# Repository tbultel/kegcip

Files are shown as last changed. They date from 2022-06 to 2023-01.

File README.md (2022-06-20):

# kegcip

CIP controller for Beer Tanks and Kegs

Inspired from various existing CIP (Clean In Place) Open Source projects, this one
aim to be a kind of best-off, leveraging the original designers spirit and 
brilliant ideas, but trying to bring more robustness, and reusability.

We only focus here on the microcontroller code and hardware.

The chosen microcontroler is the Teensy 4.0
The application works fine with Teensy 3.1 as well, but it is end of life and sold out.

For simplicity and readabiliy, the code stronly relies on TeensyThreads https://github.com/ftrias/TeensyThreads

# Setup

You need an arduino + teensy toolchain setup, please see on Teensy site how to make it.
The top Makefile lists the needed librairies, that can be installed, for instance,
via the Arduino IDE.

* U8g2: graphical library for SSD1309 LCD chips. Uses hardware SPI.
* Wire: i2C support (for the relays board)
* DallasTemperature: to read the temperature sensor, needs OneWire
* SPI: see above
* RotaryEncoder: support of rotary buttn plugged on GPIOs
* OneWire: see above
* TeensyThreads: for modern and efficient code !
* Bounce2: de-bouncing GPIO in reads
* EEPROM: support of built-in EEPROM in Teensy board, for horameters

# Building

Clone with recurse option, or perform a 
``` 
git submodule update --init
```
Then it's simple:

``` 
make clean && make -j && make flash
```

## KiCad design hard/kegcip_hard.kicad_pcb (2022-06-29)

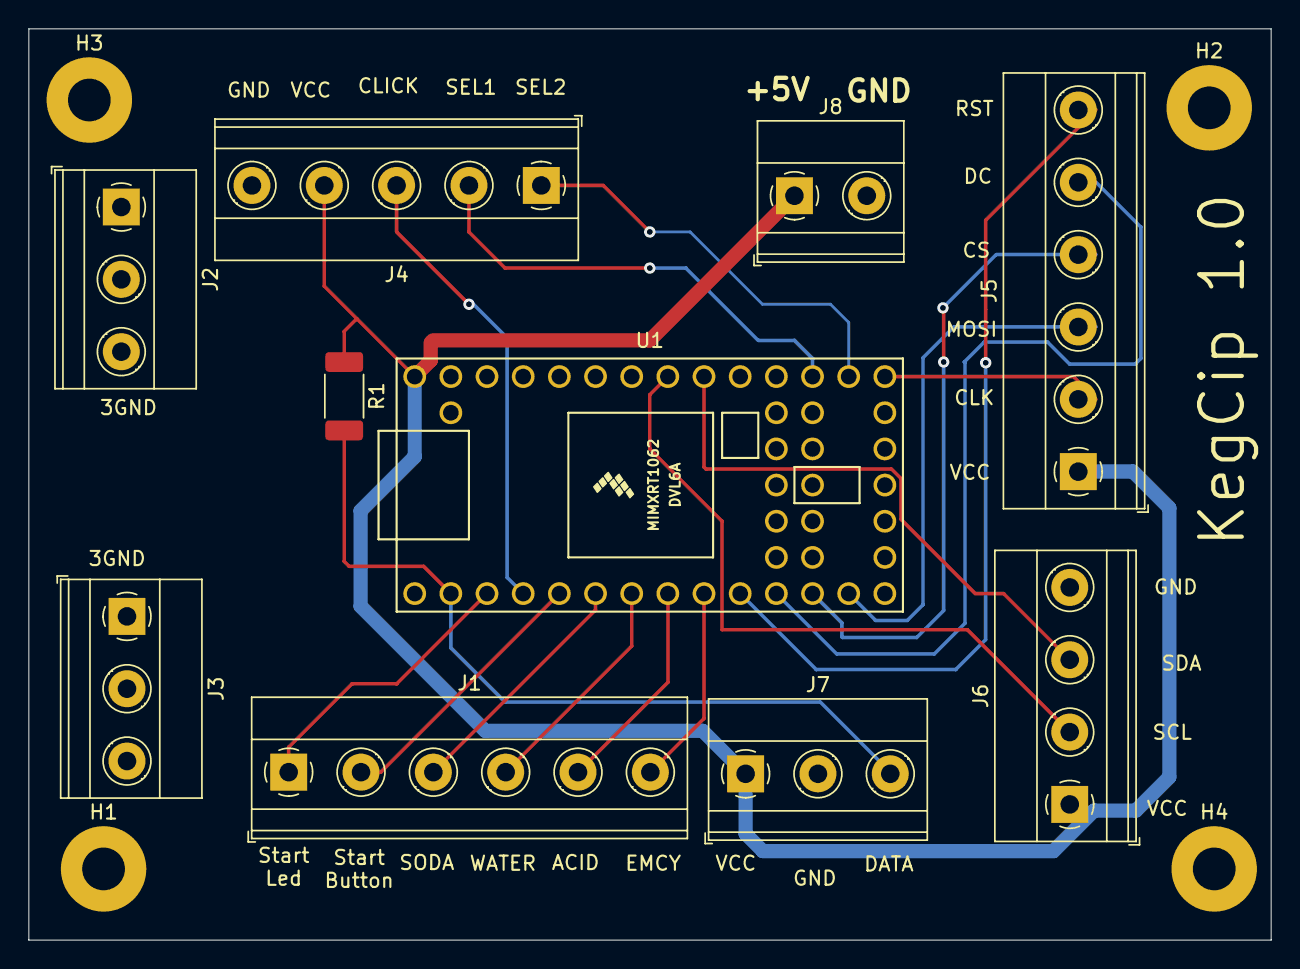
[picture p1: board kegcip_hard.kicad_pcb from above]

Board: 2 copper layers, 87.2 x 64.0 mm, 14 parts (0 on the bottom side), 19 nets.

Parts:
H1, H2, H3, H4: MountingHole; MountingHole_3mm_Pad
J1: I/O; TerminalBlock_Phoenix_MKDS-1,5-6-5.08_1x06_P5.08mm_Horizont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
J2: GND1; TerminalBlock_Phoenix_MKDS-1,5-3-5.08_1x03_P5.08mm_Horizont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
J3: GND2; TerminalBlock_Phoenix_MKDS-1,5-3-5.08_1x03_P5.08mm_Horizont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
J4: ROTARY; TerminalBlock_Phoenix_MKDS-1,5-5-5.08_1x05_P5.08mm_Horizont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
J5: LCD; TerminalBlock_Phoenix_MKDS-1,5-6-5.08_1x06_P5.08mm_Horizont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
J6: Relays; TerminalBlock_Phoenix_MKDS-1,5-4-5.08_1x04_P5.08mm_Horizont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
J7: Temp; TerminalBlock_Phoenix_MKDS-1,5-3-5.08_1x03_P5.08mm_Horizont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
J8: PWR; TerminalBlock_Phoenix_MKDS-1,5-2-5.08_1x02_P5.08mm_Horizont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
R1: 47k; R_2010_5025Metric_Pad1.40x2.65mm_HandSolder
U1: Teensy4.0; Teensy40

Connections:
+5V: J4.4, J5.1, J6.1, J7.1, J8.1, R1.1, U1.33 (VIN)
/ACID_LOW: J1.5, U1.8 (6_OUT1D)
/EMERGENCY_STOP: J1.6, U1.9 (7_RX2_OUT1A)
/LCD_CLK: J5.2, U1.20 (13_SCK_CRX1_LED)
/LCD_DC: J5.5, U1.11 (9_OUT1C)
/LCD_RST: J5.6, U1.10 (8_TX2_IN1)
/LCD_SPI_CS: J5.4, U1.12 (10_CS_MQSR)
/LCD_SPI_MOSI: J5.3, U1.13 (11_MOSI_CTX1)
/ROT_CLICK: J4.3, U1.4 (2_OUT2)
/ROT_SEL1: J4.2, U1.22 (15_A1_RX3_SPDIF_IN)
/ROT_SEL2: J4.1, U1.21 (14_A0_TX3_SPDIF_OUT)
/SCL: J6.2, U1.26 (19_A5_SCL0)
/SDA: J6.3, U1.25 (18_A4_SDA0)
/SODA_LOW: J1.3, U1.6 (4_BCLK2)
/START_BUTTON: J1.2, U1.5 (3_LRCLK2)
/START_LED: J1.1, U1.3 (1_TX1_CTX2_MISO1)
/TEMP_DATA: J7.3, R1.2, U1.2 (0_RX1_CRX2_CS1)
/WATER_LOW: J1.4, U1.7 (5_IN2)
GND: H1.1, H2.1, H3.1, H4.1, J2.1, J2.2, J2.3, J3.1, J3.2, J3.3, J4.5, J6.4, J7.2, J8.2, U1.1 (GND), U1.17 (GND), U1.32 (GND)

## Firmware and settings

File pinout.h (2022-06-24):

#pragma once

// kegcip needs 14 GPIOS and 3 HW spi pins
// (think about when wanting to replace the µC !)

#define PIN_ONE_WIRE_BUS	0

#define PIN_BUTTON_LED		1
#define PIN_MENUCLICK		2
#define PIN_START_BUTTON	3
#define PIN_SODA_LOW		4
#define PIN_WATER_LOW		5
#define PIN_ACID_LOW		6
#define PIN_EMERGENCY_STOP	7

#define PIN_LCD_RST			8
#define PIN_LCD_DC			9
#define PIN_LCD_SPI_CS		10	// HW SPI
#define PIN_LCD_SPI_MOSI	11	// HW SPI
#define PIN_LCD_SPI_CLK		13	// HW SPI

#define PIN_MENUSELECT_1	14
#define PIN_MENUSELECT_2	15

#define PIN_RELAYS_SDA		18
#define PIN_RELAYS_SCL		19

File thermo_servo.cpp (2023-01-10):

#include <Arduino.h>
#include <stdio.h>

#include "thermo_servo.h"
#include "thread.h"
#include "temperature.h"
#include "relays.h"
#include "logical_output.h"
#include "display.h"
#include "main_menu.h"
#include "start_button.h"
#include "cycles.h"
#include "rotary_button.h"

static float thermo_setpoint = 0.0;
static float thermo_target_setpoint = THERMO_SERVO_TEMP_DEFAULT;

static int thermoServoThreadId = -1;
static bool thermo_is_on = false;
static bool initialized = false;
static bool ready = false;

static void thermo_servo_set_setpoint(float setpoint);
static void thermo_servo_set_target_setpoint(float target_setpoint);

#define THERMO_SERVO_THREAD_PERIOD_MS	500

static void thermo_servo_thread() {
	ready = true;
	printf("Thermo thread ready\n");

	bool heating = false;
	bool alarm = false;

	float old_temp = 0.0;
	uint32_t oldtimeSecs = 0;

	while (true) {
		float temp = temperature_get();

		char tempS[8], setpointS[8];
		dtostrf(temp, 4, 2, tempS);
		dtostrf(thermo_setpoint, 4, 2, setpointS);
#if DEBUG
		printf("%s: temp %s/%s\n", __func__, tempS, setpointS);
#endif		

		if (thermo_is_on && temp < thermo_setpoint) {
			if (!heating) {
				printf("%s: heating ...\n", __func__);
				old_temp=temperature_get();
				oldtimeSecs=millis()/1000;
			}

			heating = true;

		}
		else {
			if (heating)
				printf("%s: stopped heating ...\n", __func__);

			heating = false;
		}

		/* check the temperature delta */
		if (heating) {
			uint32_t elapsedSecs = millis()/1000;

			printf("thermal countdown: %d\n", THERMO_SERVO_1_DEG_TIME_SECS - (elapsedSecs - oldtimeSecs));

			// Check the temperature change each THERMO_SERVO_1_DEG_TIME_SECS interval, expect it to rise of at least 1 deg C
			if (elapsedSecs - oldtimeSecs >= THERMO_SERVO_1_DEG_TIME_SECS) {
				oldtimeSecs = elapsedSecs;

				char old_tempS[8];
				dtostrf(old_temp, 4, 2, old_tempS);

				printf("Check temp rising (old %s (%d), current %s (%d))\n", old_tempS, (int)old_temp, tempS, (int)temp);

				// Do not check the temperature delta if it is decreasing. (can happen when fresh soda comes back into the tank)
				if (temp > old_temp && (temp-old_temp < 1.0)) {
					alarm = true;
				}
				old_temp = temp;
			}
		}

		// check the heating timeout 
		if (alarm) {
			cycle_stop();
			thermo_off();
			logical_output_set(RELAYS_OFF);
			main_menu_disable();
			start_button_disable();
			rotary_button_disable();
			display_set_context(ALARM_CONTEXT);
			printf("ERROR: temperature runwaway !\n");
			// Dies here
			for (;;) {}
		}

		if (heating) {
			display_heating(true);
			relays_set_relay_on(THERM);
		}
		else {
			display_heating(false);
			relays_set_relay_off(THERM);
		}

		threads.delay(THERMO_SERVO_THREAD_PERIOD_MS);
	}
}

void thermo_servo_init() {
	if (initialized)
		return;

	printf("** Initializing thermo servo thread\n");
	thermoServoThreadId = threads.addThread(thermo_servo_thread, 0);
	while (!ready) { delay(100); }
}

static void thermo_servo_set_setpoint(float setpoint) {

	if (setpoint < 0.0)
		setpoint = 0.0;

	if (setpoint > THERMO_SERVO_TEMP_MAX)
		setpoint = THERMO_SERVO_TEMP_MAX;

	thermo_setpoint = setpoint;

	char tempS[8];
    dtostrf(thermo_setpoint, 4, 1, tempS);
	printf("thermo setpoint set to %s\n", tempS);
	
	display_thread_wakeup();
}

float thermo_servo_get_setpoint(void) {
	return thermo_setpoint;
}

void thermo_on(void) {
	printf("%s\n", __func__);
	if (!thermo_is_on)
		thermo_servo_set_setpoint(thermo_target_setpoint);
	thermo_is_on = true;
}

void thermo_off(void) {
	printf("%s\n", __func__);	
	if (thermo_is_on)
		thermo_servo_set_setpoint(0.0);	
	thermo_is_on = false;
}

bool thermo_set_enzyme_setpoint(void) {
	thermo_servo_set_target_setpoint(THERMO_SERVO_TEMP_ENZYME);
	return true;
}

bool thermo_set_standard_setpoint(void) {
	thermo_servo_set_target_setpoint(THERMO_SERVO_TEMP_DEFAULT);
	return true;
}

static void thermo_servo_set_target_setpoint(float target_setpoint) {
	char tempS[8];
    dtostrf(target_setpoint, 4, 1, tempS);
	printf("thermo thermo_target_setpoint set to %s\n", tempS);
	thermo_target_setpoint = target_setpoint;
	if (thermo_is_on)
		thermo_servo_set_setpoint(thermo_target_setpoint);
}

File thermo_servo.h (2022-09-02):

#pragma once

// TODO findout the right value for the application
#define THERMO_SERVO_TEMP_MAX		90
#define THERMO_SERVO_TEMP_DEFAULT	80
#define THERMO_SERVO_TEMP_ENZYME	50

// max number of seconds to rise the temp of 1 deg C
#define THERMO_SERVO_1_DEG_TIME_SECS	240

extern void thermo_servo_init();

extern float thermo_servo_get_setpoint(void);

extern void thermo_on(void);
extern void thermo_off(void);

extern bool thermo_set_enzyme_setpoint(void);
extern bool thermo_set_standard_setpoint(void);

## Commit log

2022-04-04 Added Arduino-Makefile submodule
2022-04-07 Fix init and menu context swap
    [bitmaps.h]
2022-04-07 added support for enzymes temperature
2022-04-08 added support for emergency button
2022-06-20 new cycles, and switched to teensy40
2022-06-24 relays: moved hardcoded SDA/SCL pin numbers to pinout.h
2022-06-29 Added ack logic, plus sets last input as pullup to get rid of 3.3v
2022-06-29 Added Kicad shematics & pcb
    [kegcip_hard.kicad_pcb, kegcip_hard.kicad_sch]
2022-06-29 kegcip.cpp: horameters must be initialized after relays
2022-08-19 thermo servo runway enhancement, simplified cycles, MPC23017 board, fast 1-wire temp request
2022-08-20 rotary button: debounce click
2022-08-26 set internal pullups on i2c lines (effective on teensy4 only)
2022-09-02 thermo_servo: increase heating time limit to 240s, and test time to 1200s
2022-09-09 .gitignore: added vscode & kicad generated files
2022-09-09 Ajout de la circulation pour thermo_test, plus 3 cycles de circulation sans chauffe
2022-09-15 horameter.cpp: fixed compilation error with latest teensy EEPROM library
2022-09-15 Makefile: Changed arduino SDK dir to /opt, and adder USER_LIB_PATH definition
2022-09-16 Une bonne journée de boulot -> cycle complet futs validé
2022-10-12 thermo servo: put back the temperature to 80 deg
2023-01-17 maintient temp, préchauffage, suppression purge circuit, durées vidange
    => maintient de la température de la soude une fois revenue dans le
    cycle complet fût
    => mais au second cycle si 79,9° alors re-préchauffage avec descente
    de temp (7 minutes pour descendre et remonter !)
    => donc dissociaiton préchauffage de cycle complet
    => problème réccurent d'amorçage sur le cycle complet fûts : la purge
    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
2023-02-17 relays: change to sync always
2023-02-17 thermo: no longer needs the water pump
2023-03-10 Rincage fermenteur : Tempo 5 min au lieu de bouton start
